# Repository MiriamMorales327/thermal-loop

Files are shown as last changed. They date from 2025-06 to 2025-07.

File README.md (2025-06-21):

# Thermal Loop
Notes

## Licensing and Citation

[][cc-by-sa]

This work is licensed under a
[Creative Commons Attribution-ShareAlike 4.0 International License][cc-by-sa].

[cc-by-sa]: http://creativecommons.org/licenses/by-sa/4.0/
[cc-by-sa-image]: https://licensebuttons.net/l/by-sa/4.0/88x31.png
[cc-by-sa-shield]: https://img.shields.io/badge/License-CC%20BY--SA%204.0-lightgrey.svg

Cite as:

MLA ...
 
in bibtex

@Misc{...,   
  author       = {{ARTS-Lab}},   
  howpublished = {GitHub},  
  title        = {...},   
  groups       = {{ARTS-L}ab},  
  url          = {https://github.com/ARTS-Laboratory/...},  
}

<p align="center">

</p>
<p align="center">
QR code for repo.

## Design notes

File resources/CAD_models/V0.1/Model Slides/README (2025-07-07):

In this folder, there are the slides to the final model as well as the extension pipes we used to expand our current Thermal Loop System. We have included both the threaded and welded versions of the one foot extension pipe.

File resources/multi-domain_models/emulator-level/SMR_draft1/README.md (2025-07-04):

**FIRST DRAFT OF THE THERMAL LOOP**

This model only includes the loop from the reactor to the steam generator and back again. It does not yet have the secondary loop.

MODEL IMAGE



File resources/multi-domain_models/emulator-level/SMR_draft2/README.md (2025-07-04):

**SECOND DRAFT OF THE EMULATOR LEVEL MODEL OF THE THERMAL LOOP**

This includes the second thermal loop with the electric generator and turbine with its related components

MODEL IMAGE


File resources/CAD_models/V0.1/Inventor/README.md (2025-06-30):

# Inventor Models
The "aafinal model" includes all the parts and pieces so when one opens the file everything will load as well. Use referenced Powerpoint to view where each part and assembly are positioned and placed.

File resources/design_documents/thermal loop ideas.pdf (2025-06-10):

# SMR Thermal Loop Ideas

## Austin Downey

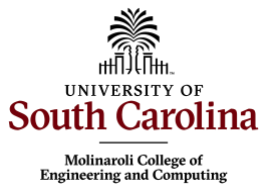
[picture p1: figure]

1

# The main idea

Keep it,

## - Safe

## - Simple

## - Easy

## - Clean

2

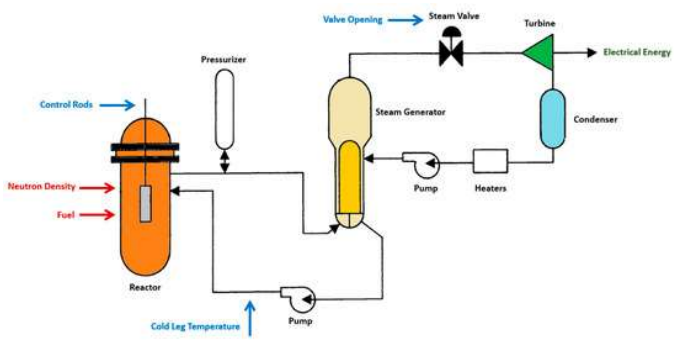
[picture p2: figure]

Basic idea, from the paper “Real-Time Simulation of a Small Modular Reactor in-the-Loop within Nuclear-Renewable Hybrid Energy Systems” https://www.mdpi.com/1996-1073/15/18/6588

# Our version

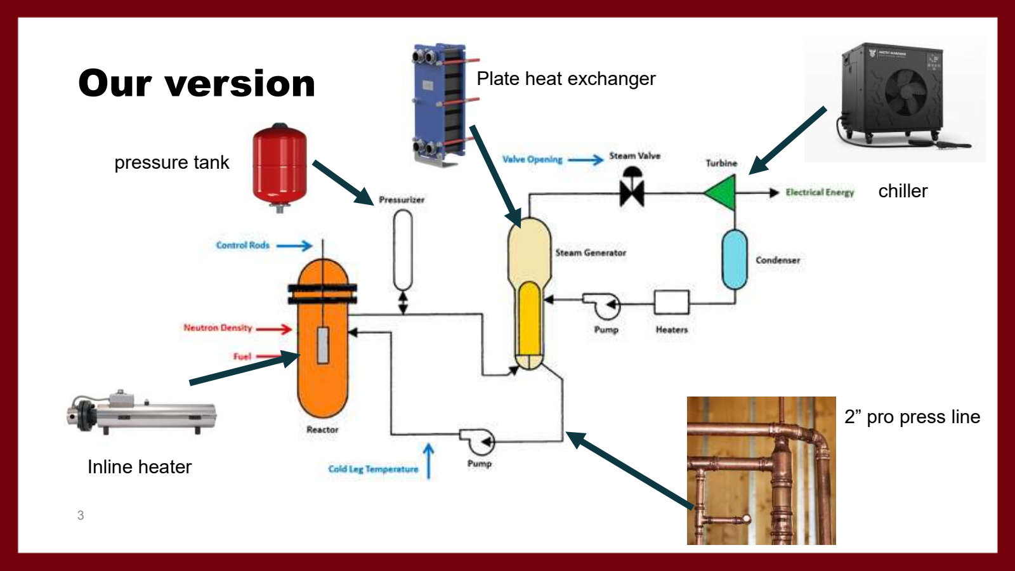
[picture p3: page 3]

3

Inline heater

chiller

pressure tank

2” pro press line

Plate heat exchanger

# Hardware we have for use

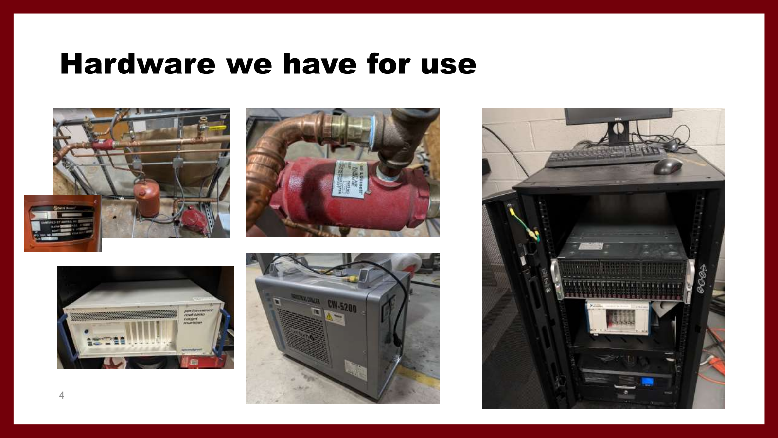
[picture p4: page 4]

4

# Hardware we have for use

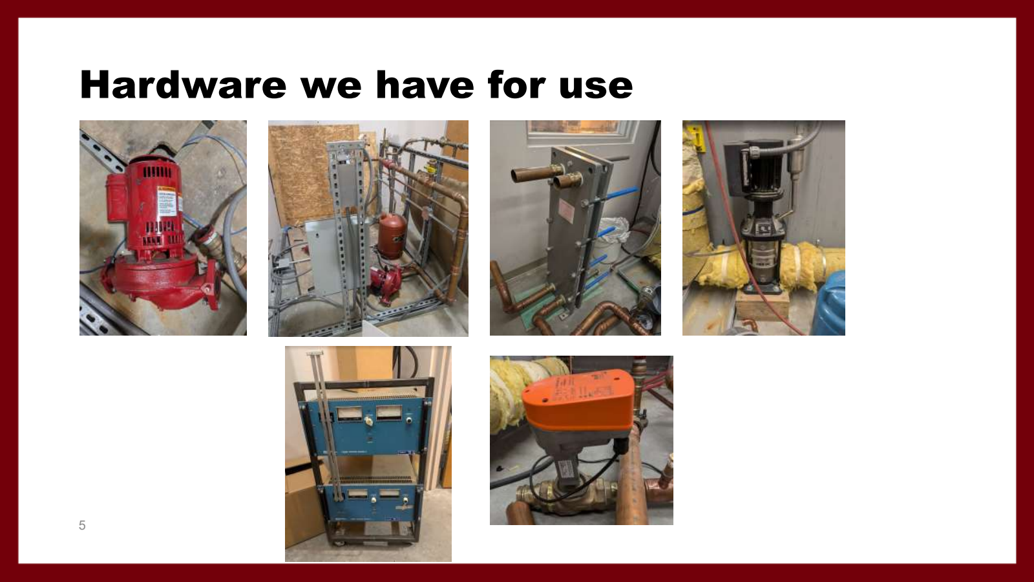
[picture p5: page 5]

5

# Thank You for Your Time

Name: Ausitn Downey
Title: Associate Professor
Email: austindowney@sc.edu
Lab GitHub: github.com/arts-laboratory

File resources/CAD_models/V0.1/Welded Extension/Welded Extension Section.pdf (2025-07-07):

# Welded Extension Section

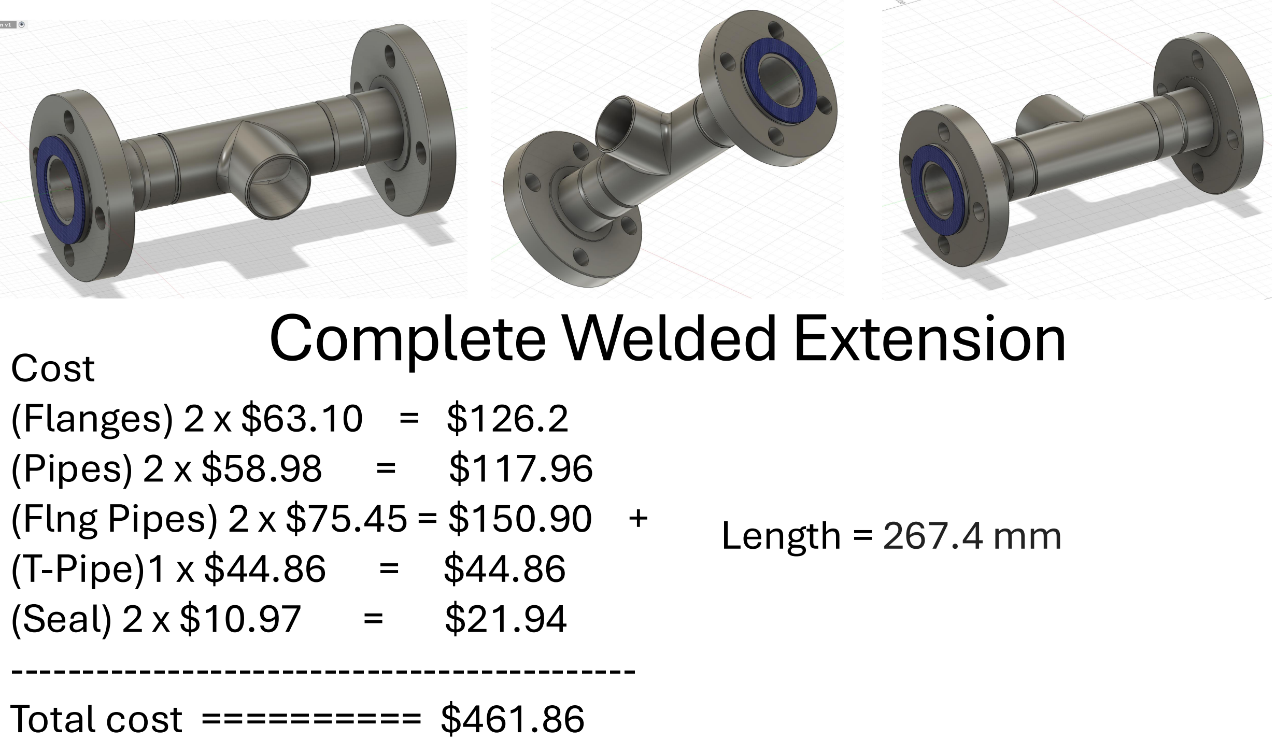
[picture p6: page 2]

## Complete Welded Extension Cost

(Flanges) 2 x $63.10 = $126.2
(Pipes) 2 x $58.98 = $117.96
(Flng Pipes) 2 x $75.45 = $150.90 +
(T-Pipe)1 x $44.86 = $44.86 (Seal) 2 x $10.97 = $21.94 --------------------------------------------Total cost ========== $461.86

Length = 267.4 mm

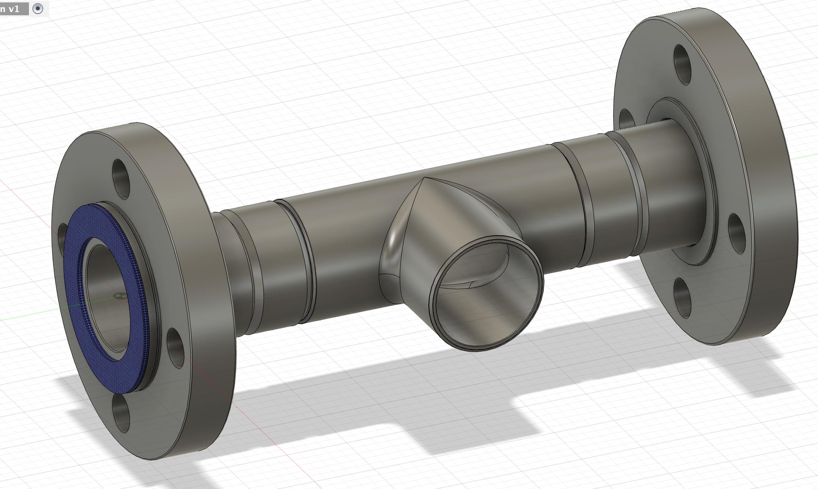
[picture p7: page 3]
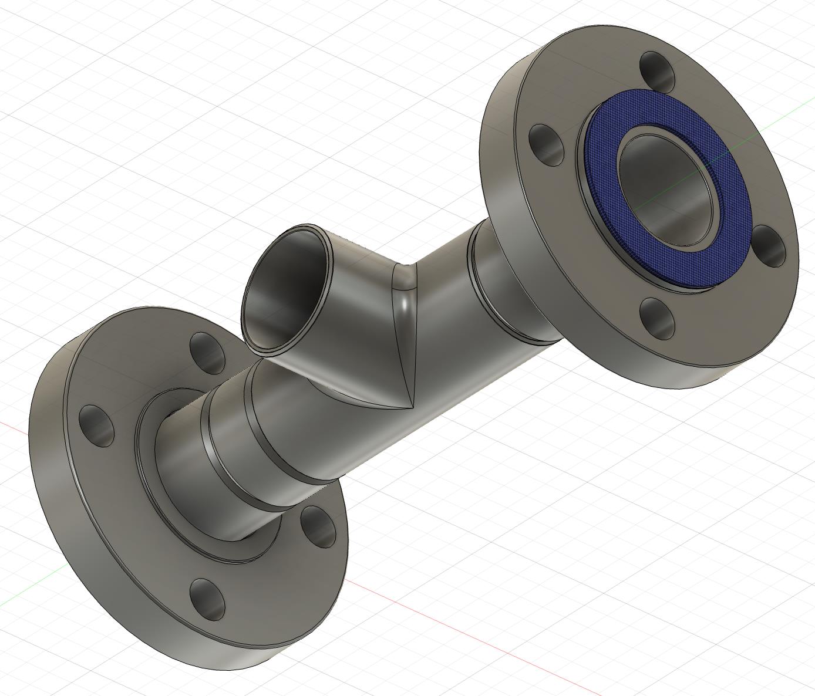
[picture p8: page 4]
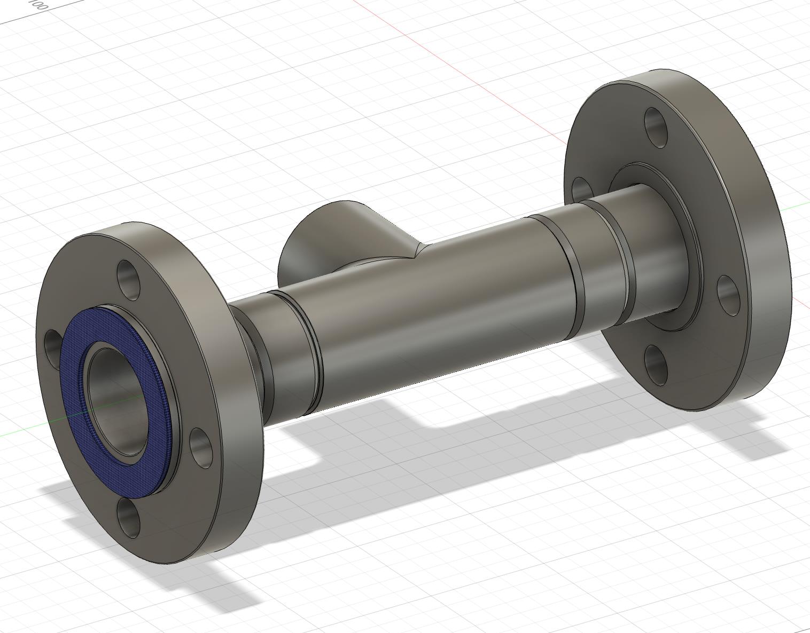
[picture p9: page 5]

## Welded Flange

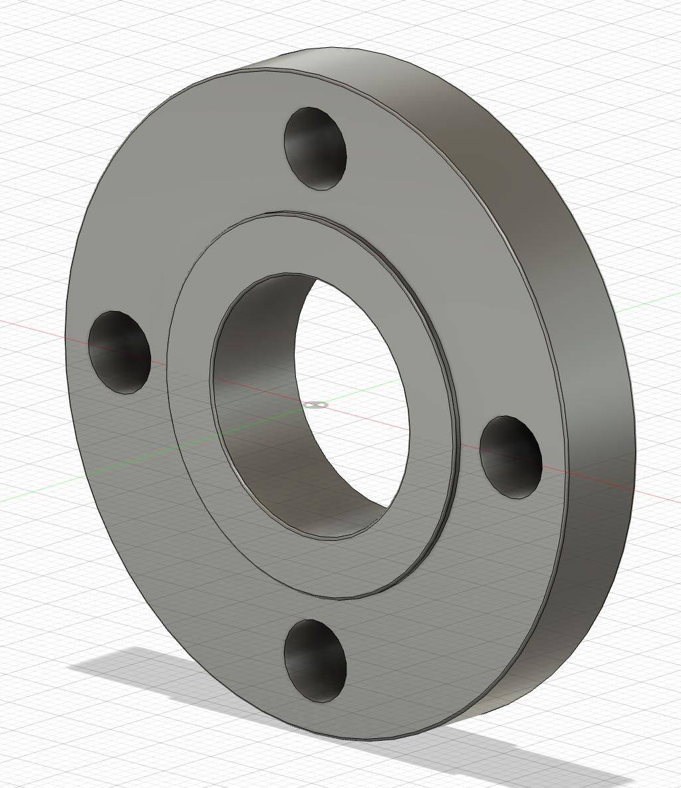
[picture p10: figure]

Cost
$63.10 each
2 flanges used
Total = $126.2
Welded Flange
Grainger Link (https://www.grainger.com/product/Pipe-Flange-Slip-On-Flange-60WJ84)

## 1 ½ Weld Extension Pipe

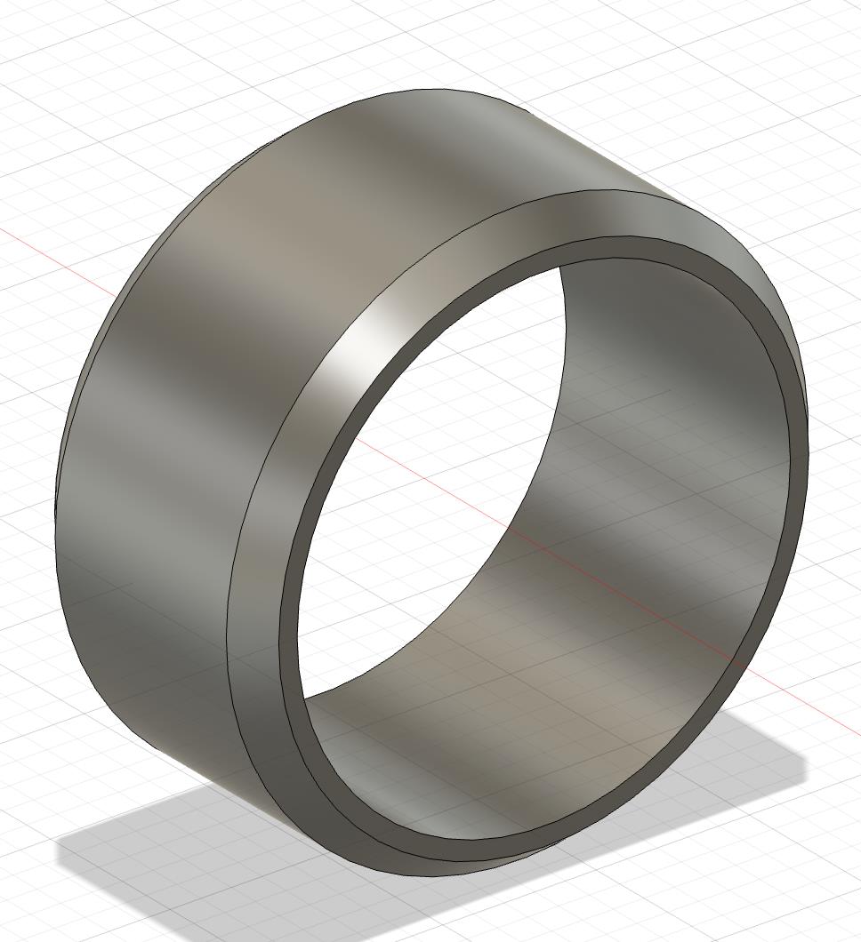
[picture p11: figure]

Cost
$58.98 each
2 pipes used
Total = $117.96

This pipe is a custom-cut 23.8 mm piece a 1 ft long pipe

Welded pipe
Grainger Link (https://www.grainger.com/product/Nipple-304-Stainless-Steel-782G43)

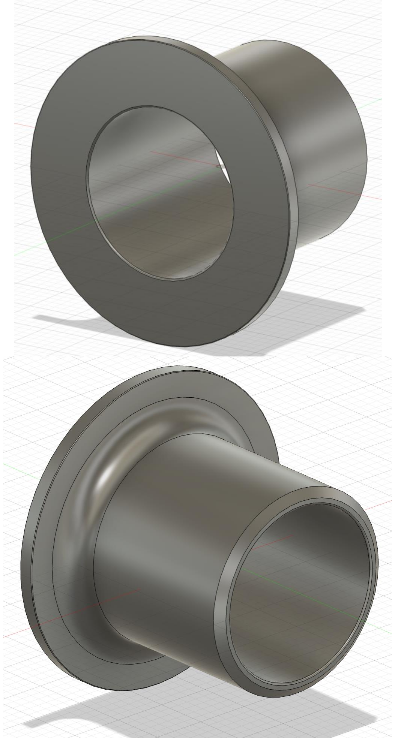
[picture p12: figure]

## Flange Step End Pipe

Cost
$75.45 each
2 Flange Pipes used
Total = $150.90

Step End Pipe
Graigner Link (https://www.grainger.com/product/Stub-End-Type-A-304L-Stainless-1RTU2)

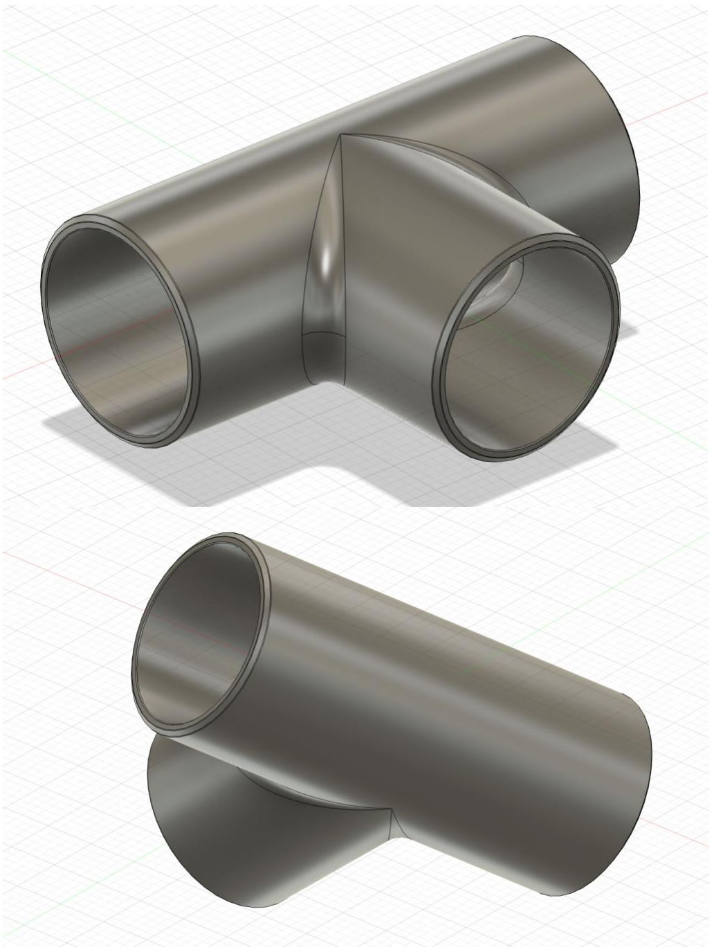
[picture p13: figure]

## Welded T-Pipe

Cost
$44.86 each
1 T-Pipe used
Total = $44.86

Welded T- (https://www.grainger.com/product/Tee-304L-Stainless-Steel-1RTR2)Pipe
Grainger Link (https://www.grainger.com/product/Tee-304L-Stainless-Steel-1RTR2)

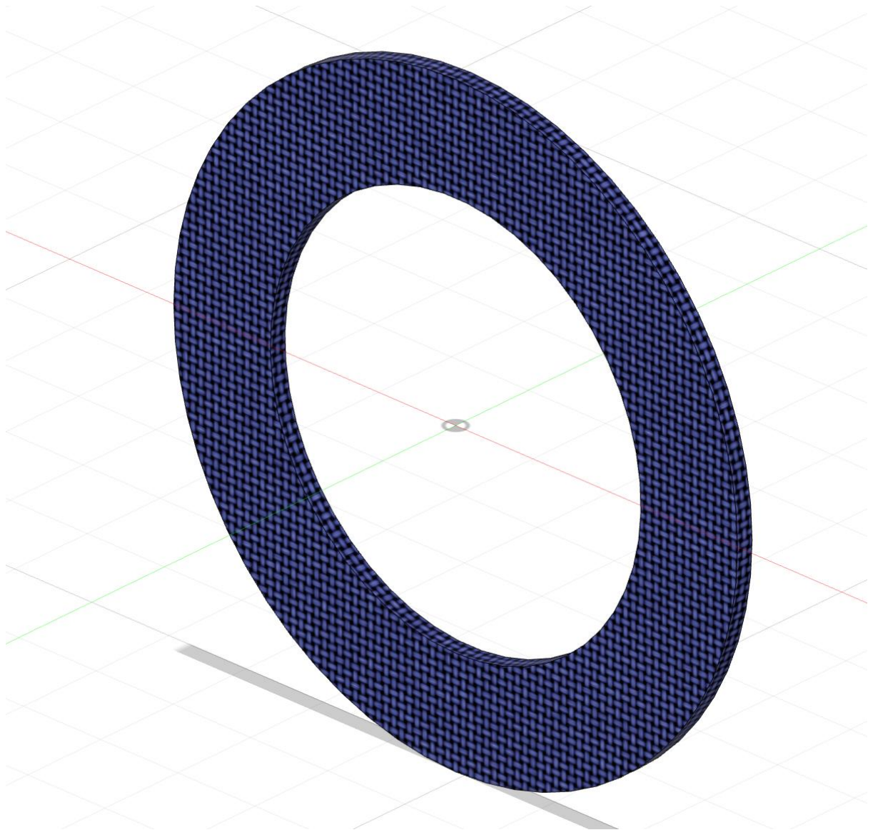
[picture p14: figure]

Flange Seal
Grainger Link (https://www.grainger.com/product/GARLOCK-Ring-Flange-Gasket-Class-150-38VR20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)

## Average Flange Blue Seal

Cost
$10.97 each
2 seals used
Total = $21.94

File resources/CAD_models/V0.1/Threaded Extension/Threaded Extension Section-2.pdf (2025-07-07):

# Threaded Extension Section

Hampton and Miriam

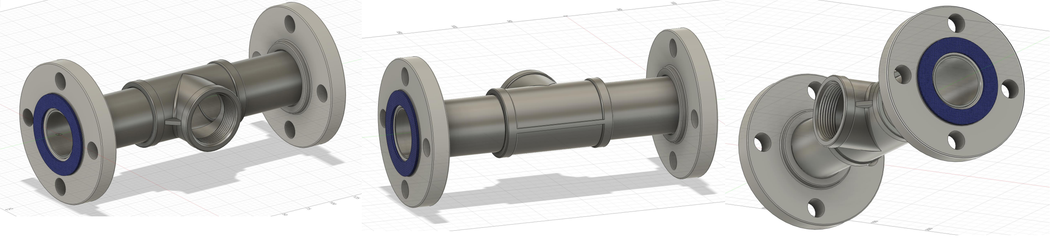
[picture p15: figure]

## Complete Threaded Extension

Cost
(Flanges) 2 x $91.86 = $183.72 (Pipes) 2 x $15.52 = $31.04 + (T-Pipe)1 x $47.70 = $47.70 (Seal) 2 x $10.97 = $21.94 --------------------------------------------Total cost ======= $284.4

Length = 267.4 mm

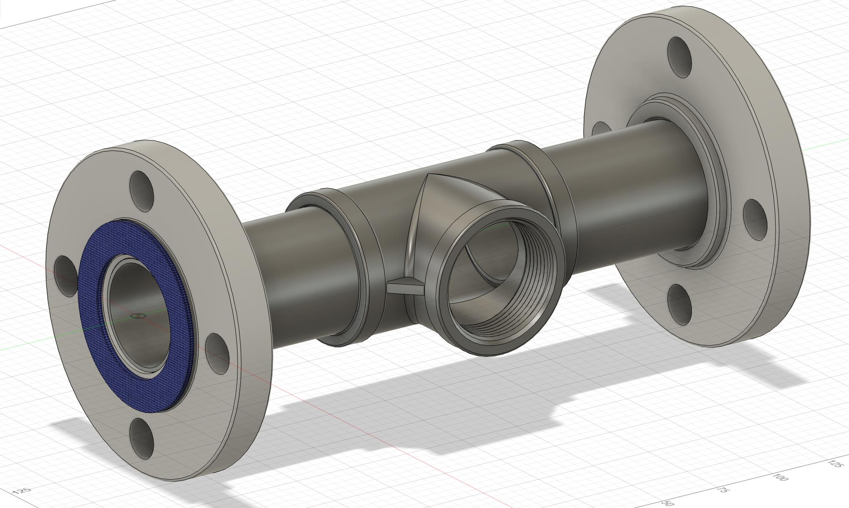
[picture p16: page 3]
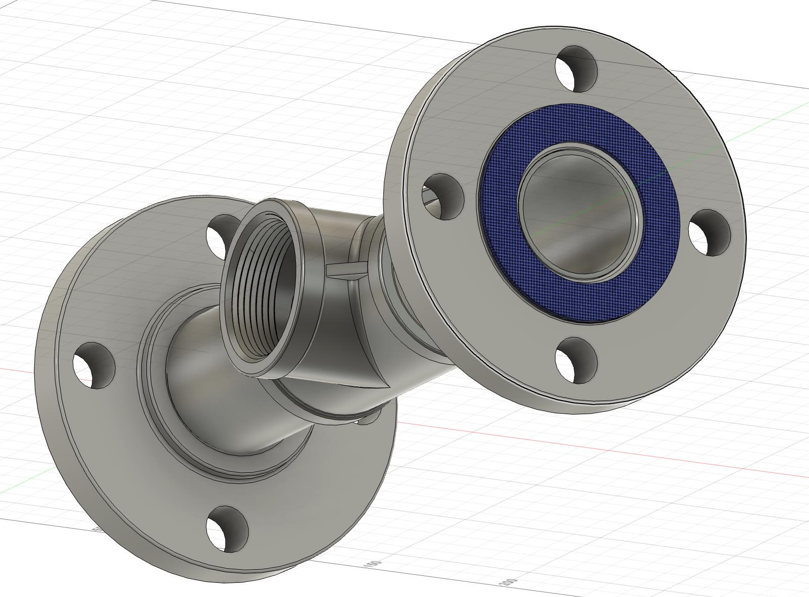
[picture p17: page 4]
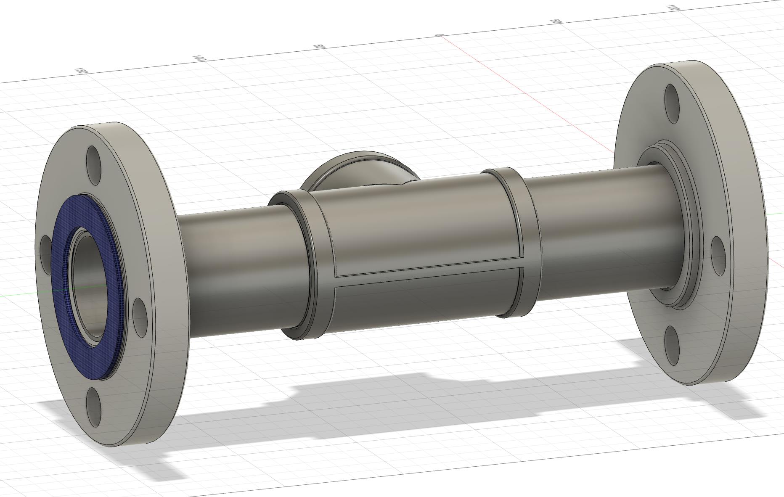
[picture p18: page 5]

# Components

## Threaded Flange

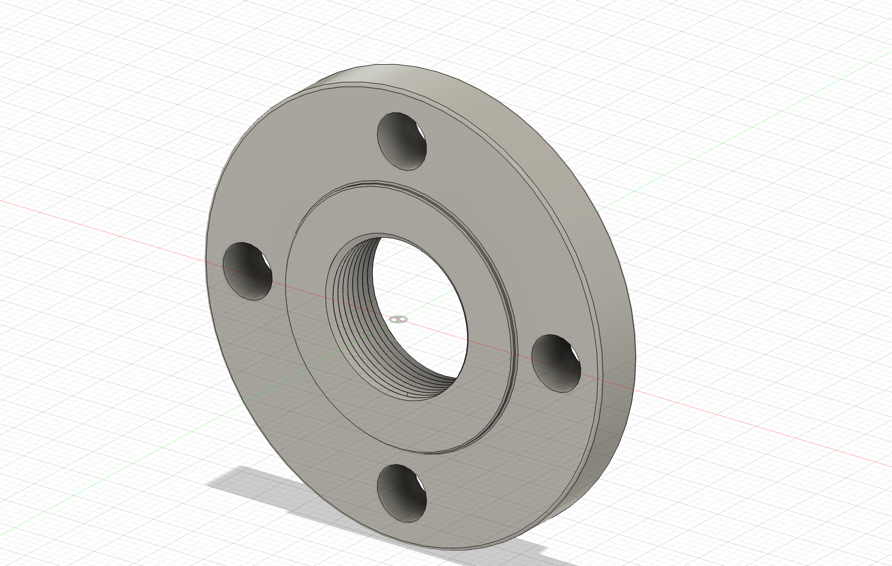
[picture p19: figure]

Cost
$91.86 each flange
2 flanges used
Total = $183.72
Threaded Flange
Grainger Link (https://www.grainger.com/product/Pipe-Flange-Floor-Flange-4WPV1)

## Threaded T-Pipe

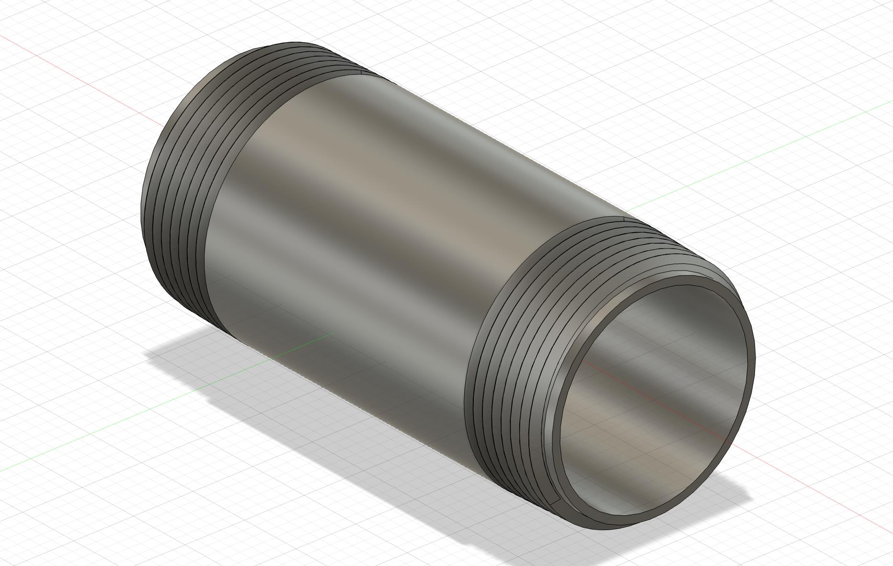
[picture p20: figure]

Cost
$15.52 each
2 pipes used
Total = $31.04
Threaded Pipe
Grainger Link (https://www.grainger.com/product/Nipple-304-Stainless-Steel-1XBC4)

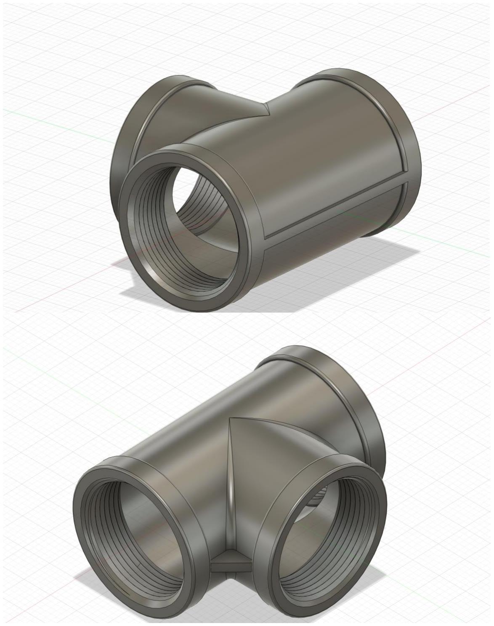
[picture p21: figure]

## Threaded T-pipe

Cost
$47.70 each
1 T-Pipe used
Total = $47.70
Threaded T- (https://www.grainger.com/product/Tee-304-Stainless-Steel-1LUA5)Pipe
Grainger Link (https://www.grainger.com/product/Tee-304-Stainless-Steel-1LUA5)


Flange Seal
Grainger Link (https://www.grainger.com/product/GARLOCK-Ring-Flange-Gasket-Class-150-38VR20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)

## Average Flange Blue Seal

Cost
$10.97 each
2 seals used
Total = $21.94

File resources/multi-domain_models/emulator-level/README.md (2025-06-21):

# Multi-domain Models

## Emulator Level
* A Simscape model of the thermal loop as built in C004G
* Used for developing a DT of the thermal loop

### What follows if from MAtt's upload. 
* Update as needed. 
**PRESSURIZED WATER REACTOR FOR A SMALL MODULAR REACTOR**

The models here conatain variations of a thermal loop for a pressurized water reactor system in a small modular reactor. 
The thermal loop consists of 2 main cycles;

~primary - the loop containg the fluid flow through the reactor to the steam generator

~secondary - the loop used to generate electricity from the steam in the steam generator


citation link; https://www.nrc.gov/reading-rm/basic-ref/students/animated-pwr.html 

[text](../README.md)

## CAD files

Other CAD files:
resources/CAD_models/V0.1/Inventor/.iam files/Air Exhaust Valve.iam
resources/CAD_models/V0.1/Inventor/.iam files/Average Flange Component (Larger Nut).iam
resources/CAD_models/V0.1/Inventor/.iam files/Average Flange Component (Larger Nut)1.iam
resources/CAD_models/V0.1/Inventor/.iam files/Average Flange Component (Larger Nut)2.iam
resources/CAD_models/V0.1/Inventor/.iam files/Average Flange Component (Larger Nut)3.iam
resources/CAD_models/V0.1/Inventor/.iam files/Average Flange Component (Larger Nut)4.iam
resources/CAD_models/V0.1/Inventor/.iam files/Average Flange Component (Larger Nut)5.iam
resources/CAD_models/V0.1/Inventor/.iam files/Average Flange Component (Larger Nut)6.iam
resources/CAD_models/V0.1/Inventor/.iam files/Average Flange Component (Larger Nut)7.iam
resources/CAD_models/V0.1/Inventor/.iam files/Average Flange Component (Larger Nut)8.iam
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

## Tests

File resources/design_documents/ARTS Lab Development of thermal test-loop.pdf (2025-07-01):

## Thermal Test Loop Overview

Optional subhead

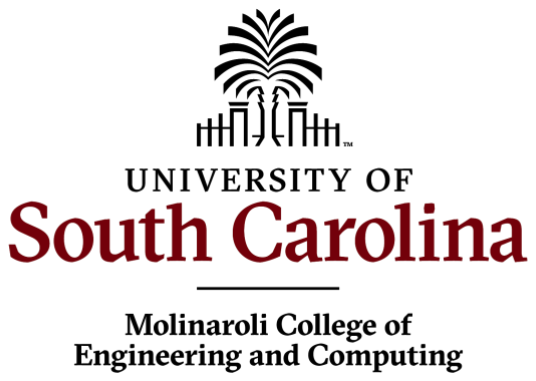
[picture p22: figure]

1

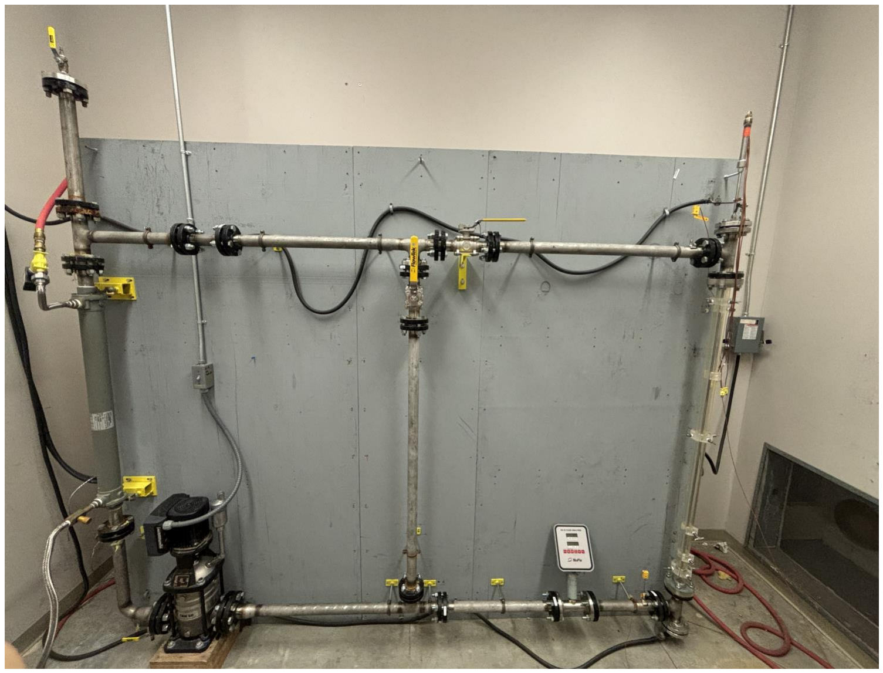
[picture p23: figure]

## Current Setup

- C004g @ 300 main
- Closed Loop
- Developed first by Dr.
Leo Carrilho in *2005*

2

## Current Setup

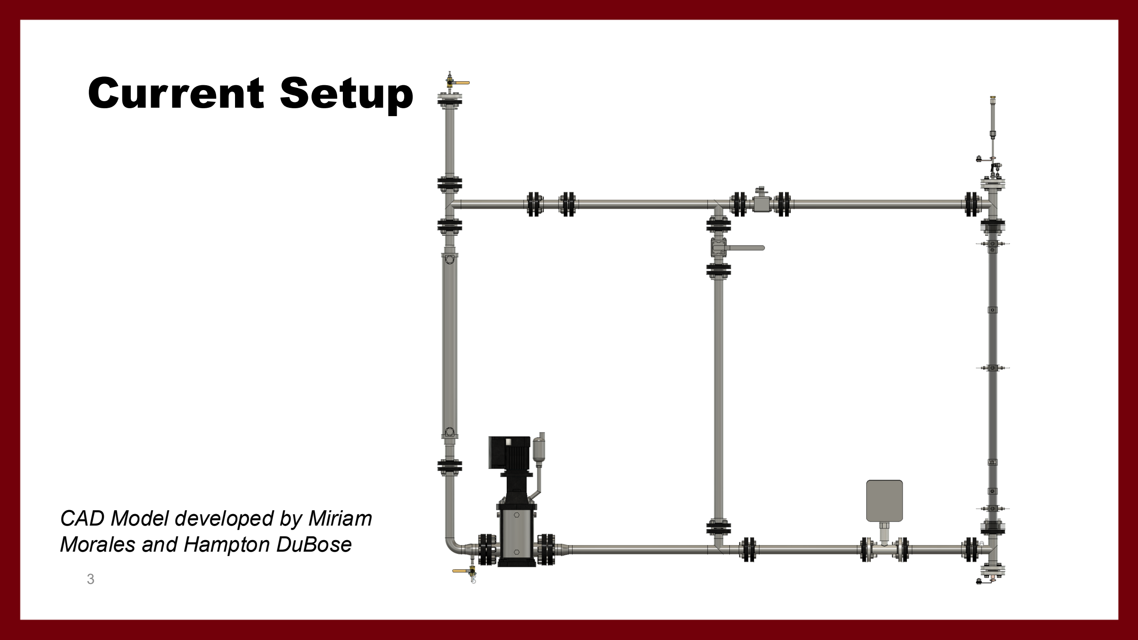
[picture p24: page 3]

3

CAD Model developed by Miriam Morales and Hampton DuBose

## Component Breakdown

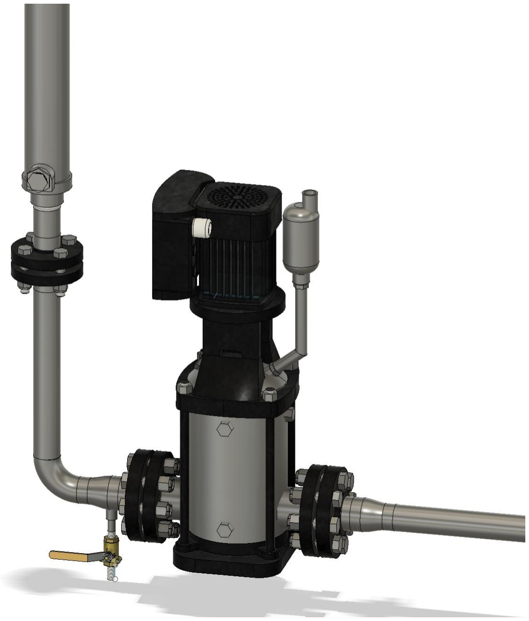
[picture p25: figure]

## Fluid Pump

- Drives coolant fluid through fuel rod containment
- Max Flowrate:14-15 m^3/hr
- 0.75 hp

5

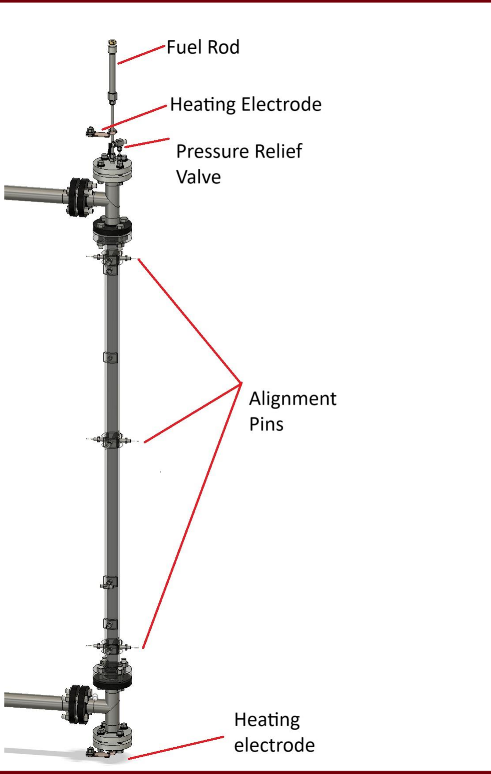
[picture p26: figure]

## Energy Source-'Reactor vessel'

- Single fuel rod secured in channel
- Plexiglass pipe for visibility
- Resistive heating adds
energy to water
- Interchangeable system for testing different fuel rods
- Has channels for pressure measurements

6

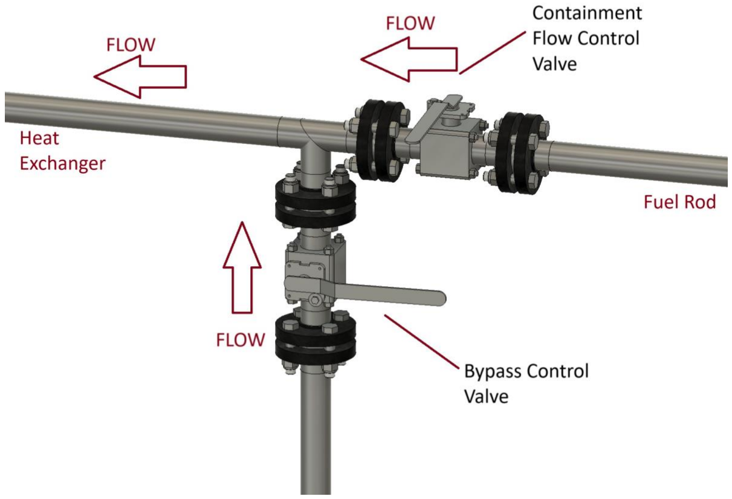
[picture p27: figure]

## Flow Control Valves

- Vertical valve
shuts/opens bypass
channel
- Changes flow rate
through heat source
- Containment Control
Valve governs flow
through heat source
- Blockage simulation

7

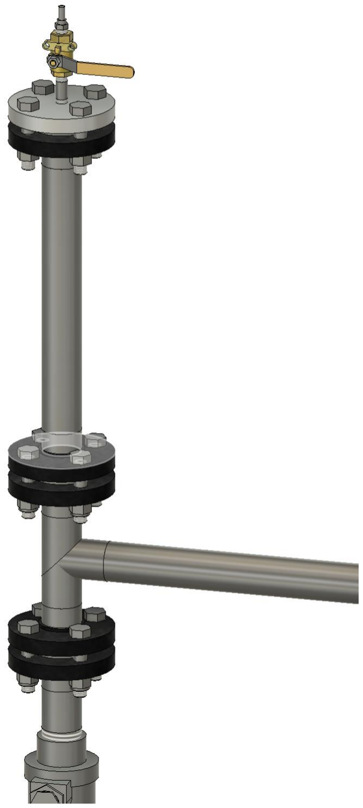
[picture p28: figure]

## Pressurizer

- Air Hose Attachment on
top
- Raises boiling point of
water by pressurizing
entire system w/ Air
- Increases efficiency of
real reactors

8

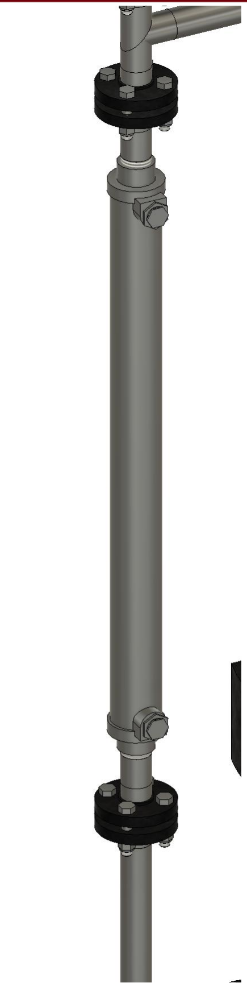
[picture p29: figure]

## Heat Exchanger

- Tap water pulls heat
from the loop
- 1 m^2 of heat transfer
area
- Water is expelled outside

9

## Typical PWR System

10

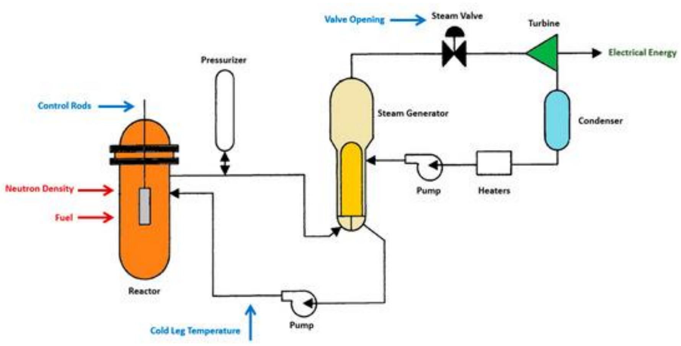
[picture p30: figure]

## Plan for expansion to add measurement instruments

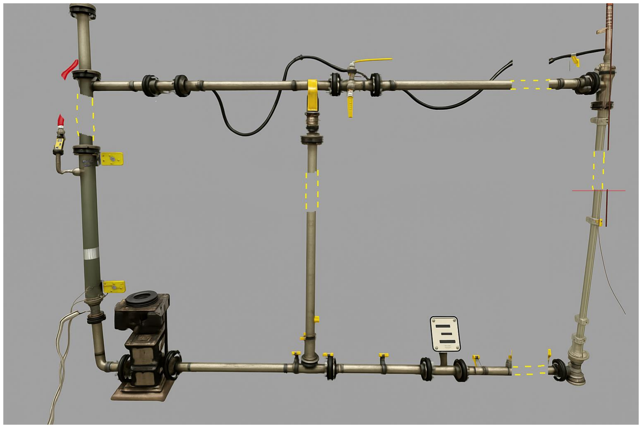
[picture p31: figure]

- Add lengths of pipe to
both horizontal and all
three vertical pipes to
Improve measurement
capability at different
locations along the
loop

11

## Plan to add 'Control Room'

12


- Develop
remote
control and
monitoring
capabilities
- Located in
C004 or
Nearby

## Thank You for Your Time

Name: Matthew Whetham

Title: Undergrad, DME
Email: mwhetham@email.sc.edu
Lab GitHub: github.com/arts-laboratory


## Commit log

2025-06-10 added power points
2025-06-21 proof of concept for piping layout and flow
2025-06-26 Create Thermal Loop Component Specs(All Specs).csv
    [Thermal Loop Component Specs(All Specs).csv]
2025-06-28 removed zipfile for inventor files
    [1 1_2 Black Flange v3.ipt, 1 1_2 Black Flange v6.ipt, 1 1_2 Silver Flange v2.ipt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]
2025-07-07 Rename resources/CAD_models/V0.1/Model Slides/Extension Pipe/Threaded/Threaded Extension Section-2.pdf to resources/CAD_models/V0.1/Threaded Extension/Threaded Extension Section-2.pdf
2025-07-07 Rename resources/CAD_models/V0.1/Model Slides/Extension Pipe/Threaded/Threaded Extension Section.pptx to resources/CAD_models/V0.1/Threaded Extension/Threaded Extension Section.pptx
